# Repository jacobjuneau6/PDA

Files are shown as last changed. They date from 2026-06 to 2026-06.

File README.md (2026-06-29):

# ESP32-S3 PDA

A simple ESP32-S3 based phone companion and pocket computer. This open-source hardware project includes a custom PCB, 3D-printable case, and Arduino firmware — everything you need to build a portable device with a color TFT display, LiPo battery management, and physical navigation buttons.

## Features

- **ESP32-S3-WROOM-1-N16R8** module (16 MB flash, 8 MB PSRAM)
- **ST7789 240×320 TFT** color display with PWM backlight control
- **MAX17048** LiPo fuel gauge for accurate battery state-of-charge
- **MCP73831** Li-Ion/Li-Po battery charger (charges via USB)
- **WS2812/NeoPixel** RGB status LED
- **3 navigation buttons** (UP, SELECT, DOWN) with active-low pull-ups
- **USB micro-B** connector for power and data
- **2-layer PCB** with Gerber files ready for fabrication
- **3D-printable case** designed in FreeCAD

## Pinout

| Silkscreen | GPIO | Function |
|---|---|---|
| SCL | 2 | SPI SCLK (TFT clock) |
| SDA | 1 | SPI MOSI (TFT data) |
| CS | 3 | TFT chip select |
| DC | 4 | TFT data/command |
| RST | 5 | TFT reset |
| BL | 6 | TFT backlight PWM |
| — | 7 | WS2812 status LED (NeoPixel) |
| — | 8 | I2C SCL (MAX17048 fuel gauge) |
| — | 9 | I2C SDA (MAX17048 fuel gauge) |
| — | 10 | Button UP |
| — | 11 | Button SELECT |
| — | 12 | Button DOWN |

**Display connector:** 1×08 pin header (GND, VCC, SCL, SDA, RST, DC, CS, BL) for ST7789 240×320 TFT, 1.54″ or 1.69″ diagonal.

**I²C address:** MAX17048 at `0x36`.

## Bill of Materials

| Reference | Qty | Part | DigiKey P/N | Description | Price  |
|---|-----|---|---|---|---|
| J1 | 1 | RAHMB20AUETR | 137-RAHMB20AUETRCT-ND | USB micro-B receptacle, right-angle, SMT (Switchcraft) | |
| LED1 | 1 | COM-16347 | 568-16347CT-ND | WS2812/NeoPixel RGB LED | |
| R1, R2 | 2 | RC1206FR-132KL | 13-RC1206FR-132KLCT-ND | 2 kΩ 1206 thick-film resistor (Yageo) | |
| SW1, SW2, SW3, SW4  | 4 | B3F-1002 | SW401-ND | Tactile switch (Omron) | |
| U1 | 1 | ESP32-S3-WROOM-1-N16R8  | 5407-ESP32-S3-WROOM-1-N16R8CT-ND | ESP32-S3 module, 16 MB flash, 8 MB PSRAM | |
| U2 | 1 | MCP73831T-2DCI/MC | MCP73831T-2DCI/MCCT-ND | Li-Ion/Li-Po battery charger IC (Microchip) | |
| U3 | 1 | TPS74533PCQWDRVRQ1 | 296-TPS74533PCQWDRVRQ1CT-ND | 3.3 V LDO voltage regulator, 500 mA (TI) | |
| U4 | 1 | MAX17048G+T10 | MAX17048G+T10CT-ND | LiPo fuel gauge IC (Maxim Integrated) | |
| U5 | 1 | AO3400A | 785-1000-1-ND | N-channel MOSFET, SOT-23 (battery protection) | |
| — | 1 | Custom PCB & stencil | JLCPCB | Fabrication | $20.00 |
| — | 1 | DigiKey components | | Components & shipping | $30.00 |
| — | 1 | 1Ah battery | | https://www.amazon.com/dp/B0DPZVBKMY?th=1 | $8.00  |
| — | 1 | Display | | https://www.amazon.com/gp/product/B0DFWLD38D/ref=ox_sc_act_title_2?smid=A2UYBS1CH53PM5 | $16.00 |

## Pictures
20260629_00h41m58s_grim
20260629_00h42m06s_grim
20260629_00h42m20s_grim
20260629_00h42m29s_grim
20260629_00h42m41s_grim
20260629_00h42m50s_grim
20260629_00h43m04s_grim
## Power Architecture

```
USB VBUS (5 V)
  ├── MCP73831 charger (U2) ──→ VBAT (battery voltage)
  │     ├── AO3400A MOSFET (U5) — battery protection
  │     └── MAX17048 fuel gauge (U4) — I²C monitoring
  │
  └── TPS74533 LDO (U3) ──→ 3.3 V rail
        ├── ESP32-S3 module (U1)
        ├── Display backlight (PWM on GPIO6)
        └── Peripherals (WS2812, buttons, I²C pull-ups)
```

- The device charges a single-cell LiPo battery via USB at 4.2 V termination.
- Battery voltage and state-of-charge are monitored by the MAX17048 over I²C.
- The 3.3 V LDO powers the MCU and peripherals from either USB or battery.

## Repository Structure

```
PDA/
├── README.md              # This file
├── BOM.csv                # Bill of Materials with DigiKey part numbers
├── Journal.md             # Design journal — case design notes & images
├── LICENSE                # MIT License
│
├── board/                 # KiCad PCB design
│   ├── board.kicad_sch    # Schematic
│   ├── board.kicad_pcb    # PCB layout
│   ├── board.kicad_pro    # Project settings
│   ├── gbrs/              # Gerber files (ready for fabrication)
│   └── staging/           # Vendor symbols, footprints, and 3D models
│
├── CAD/                   # FreeCAD mechanical design
│   ├── Assembly.FCStd     # Full assembly (PCB + case + battery + display)
│   ├── case.FCStd         # 3D-printable enclosure
│   ├── battery.FCStd      # Dummy battery model (fit check)
│   ├── display.FCStd      # Dummy display model (fit check)
│   └── PCB.step           # PCB STEP export
│
└── CODE/                  # Firmware
    └── test/
        ├── platformio.ini # PlatformIO build configuration
        └── src/
            └── main.cpp   # Arduino demo sketch
```

## Firmware

The demo firmware exercises all major subsystems: display, battery gauge, status LED, and buttons.

### Build & Flash

**Prerequisites:** [PlatformIO](https://platformio.org/install) (VS Code extension or CLI).

```bash
cd CODE/test

# Build
pio run

# Flash and open serial monitor (115200 baud)
pio run --target upload --target monitor
```

### What the Demo Does

1. **Boot splash** — "ESP32-S3 PDA / Boot OK" on the TFT, WS2812 glows blue
2. **Battery readout** — cell voltage and state-of-charge, updates ~6× per second
3. **Button indicators** — shows pressed button (UP/SELECT/DOWN) on the TFT
4. **LED feedback** — WS2812 colour changes:
   - Purple = idle
   - Green = SELECT
   - Red = UP
   - Blue = DOWN
5. **Serial debug** — prints voltage, SOC, and button state at 115200 baud

### Libraries

| Library | Version |
|---|---|
| Adafruit GFX | ≥1.11 |
| Adafruit ST7735/ST7789 | ≥1.10 |
| Adafruit MAX1704X | ≥1.0 |
| FastLED | ≥3.7 |

All are fetched automatically by PlatformIO via `lib_deps`.

### Board Configuration

| Setting | Value |
|---|---|
| Board | ESP32-S3 DevKitC-1 |
| Framework | Arduino |
| Monitor baud | 115200 |

### Customisation

- **Backlight level** — call `backlightWrite(0..255)` in `loop()` (e.g., dim after inactivity)
- **Rotation** — change `tft.setRotation(1)` (0–3) if your panel is mounted differently
- **I²C pins** — edit `I2C_SDA` and `I2C_SCL` at the top of `main.cpp`

## PCB

- **Layers:** 2-layer board
- **Software:** KiCad 8
- **Gerber files:** Ready for fabrication in [`board/gbrs/`](board/gbrs/)
- **View online:** [Kicanvas](https://kicanvas.org/?github=https://github.com/jacobjuneau6/PDA/blob/main/board/board.kicad_pcb) — interactive board viewer (no KiCad install needed)

The PCB uses all surface-mount components. Most ICs are in small-outline packages (SOT-23, TDFN, WSON). The display connects via a standard 1×08 2.54 mm pitch pin header.

## Case

Designed in FreeCAD with a boxy, sharp-edged aesthetic. The case holds:
- The custom PCB
- A single-cell LiPo battery
- The ST7789 TFT display (1.54″ or 1.69″)

Dummy battery and display models are included for fit checking in the assembly.

## License

MIT License — see [LICENSE](LICENSE) for details.

Copyright (c) 2026 jacobjuneau6

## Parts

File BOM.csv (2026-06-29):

Reference | Qty | DigiKey_Part_Number
J1 | 1 | 137-RAHMB20AUETRCT-ND
LED1 | 1 | 568-16347CT-ND
R1,R2 | 2 | 13-RC1206FR-132KLCT-ND
SW1,SW2,SW3,SW4 | 4 | SW401-ND
U1 | 1 | 5407-ESP32-S3-WROOM-1-N16R8CT-ND
U2 | 1 | MCP73831T-2DCI/MCCT-ND
U3 | 1 | 296-TPS74533PCQWDRVRQ1CT-ND
U4 | 1 | MAX17048G+T10CT-ND
U5 | 1 | 785-1000-1-ND

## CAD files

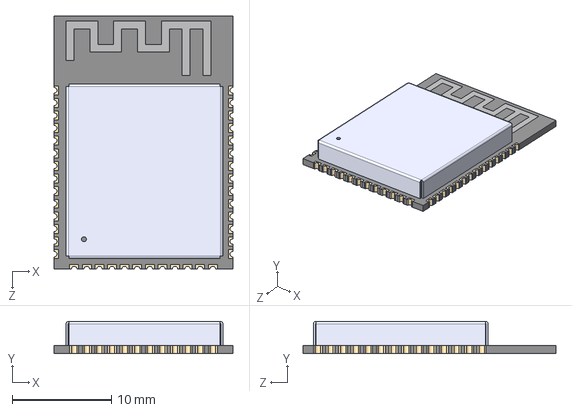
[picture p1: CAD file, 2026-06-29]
board/staging/ESP32-S3-WROOM-1-N16R8.STEP
18.0 x 3.25 x 25.5 mm

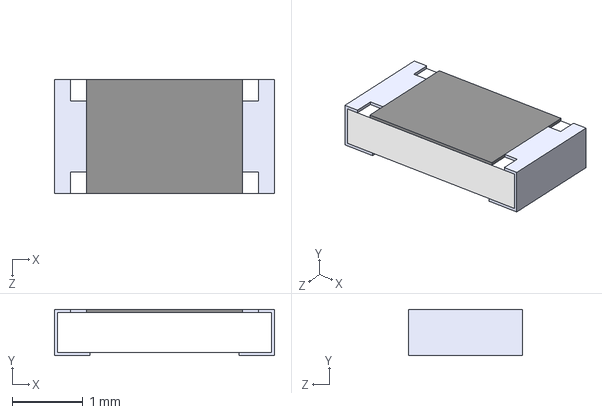
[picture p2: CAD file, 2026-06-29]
board/staging/RC1206FR-132KL/RC1206FR-132KL.step
3.10 x 0.65 x 1.60 mm

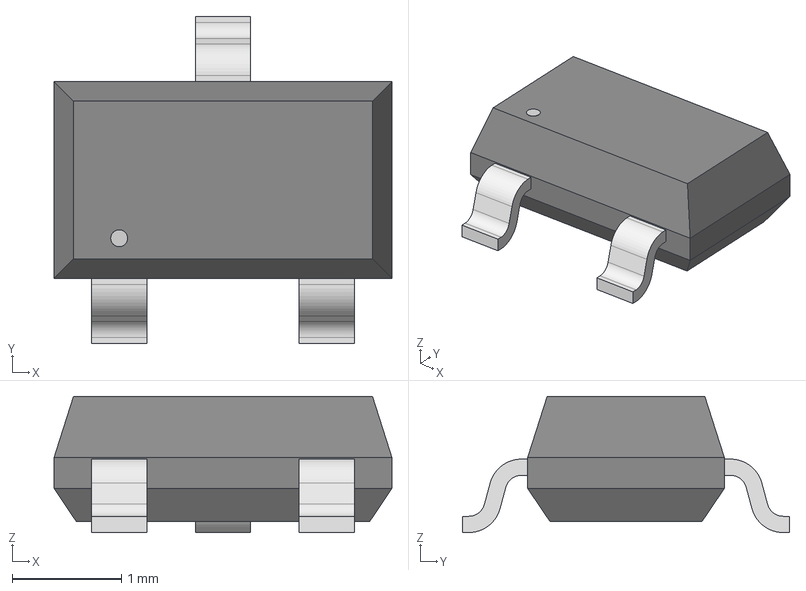
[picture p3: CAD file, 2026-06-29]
board/staging/ul_AO3400A/SOT-23-3L_AOS.step
3.10 x 3.00 x 1.25 mm

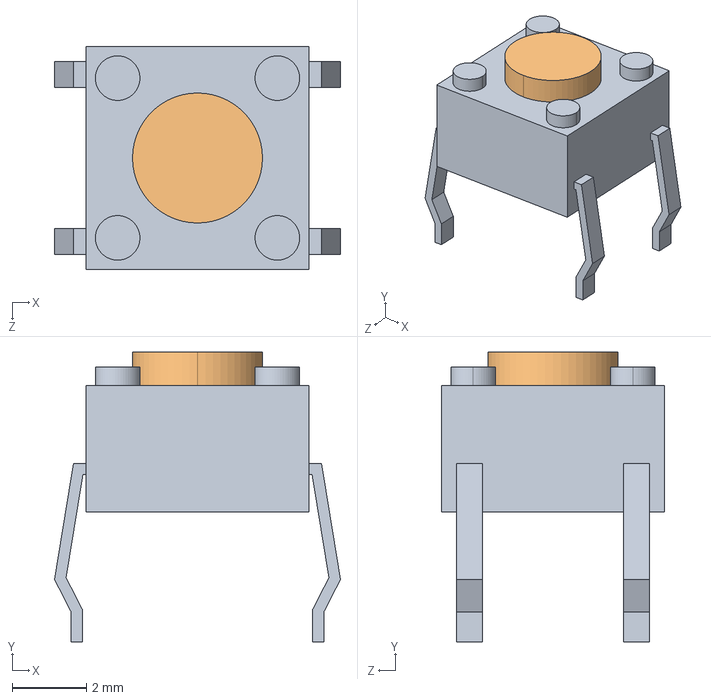
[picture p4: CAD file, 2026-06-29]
board/staging/ul_B3F-1002/B3F_1002.step
7.70 x 7.80 x 6.00 mm
B3F_1005_BASE
B3F_1005_BUTTON

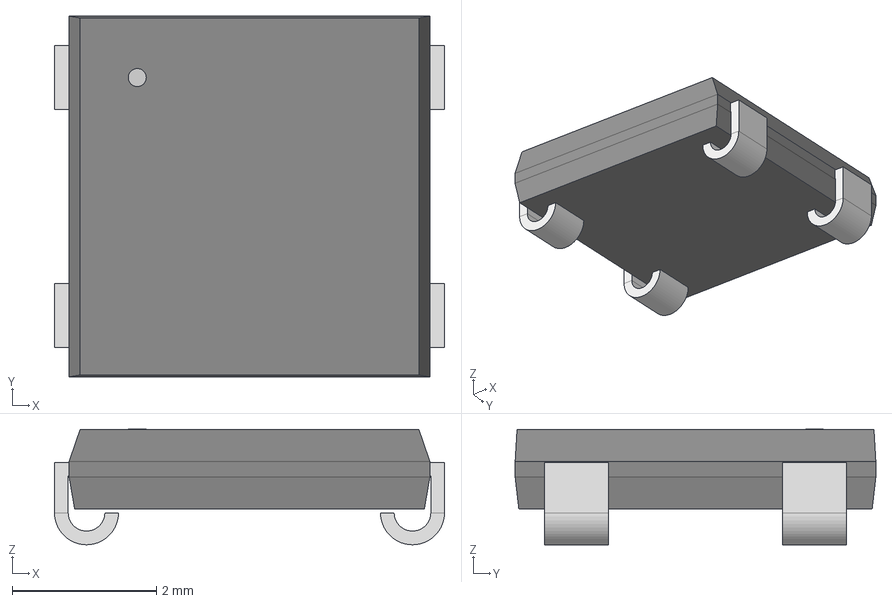
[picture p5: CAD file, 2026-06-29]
board/staging/ul_COM-16347/COM-16347_SPK.step
5.41 x 5.00 x 1.60 mm

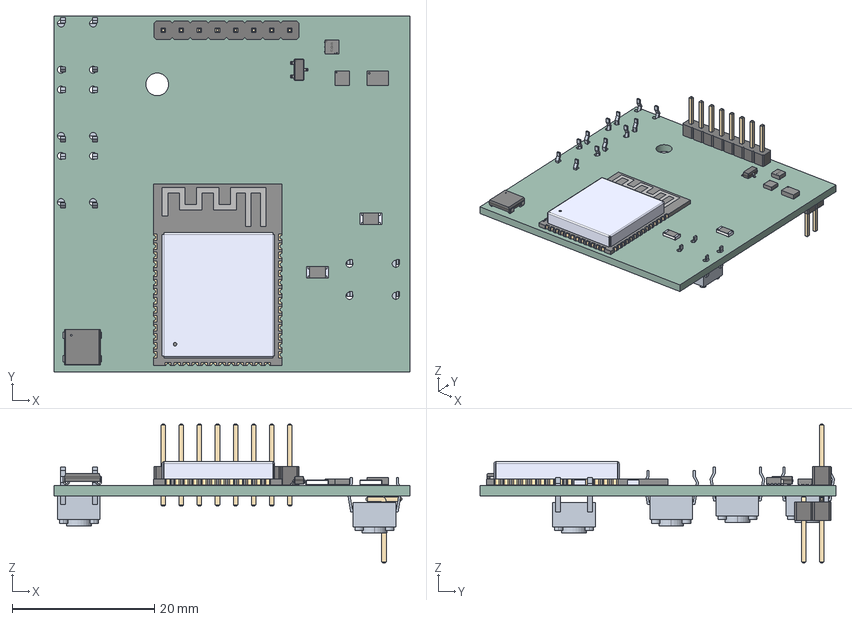
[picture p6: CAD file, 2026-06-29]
CAD/PCB.step
50.0 x 50.0 x 19.5 mm
ESP32-S3-WROOM-1-N8R2
B3F_1005_BASE x 4
B3F_1005_BUTTON x 4
MAX17048G+T10
PinHeader_1x08_P254mm_Vertical
AA1206FR-07100KL x 2
MCP73831-2ACI_MC
WSON-6_L2.0-W2.0-H0.8-P0.65
SOT-23
PinHeader_1x02_P254mm_Vertical_SMD_Pin1Left
board_PCB

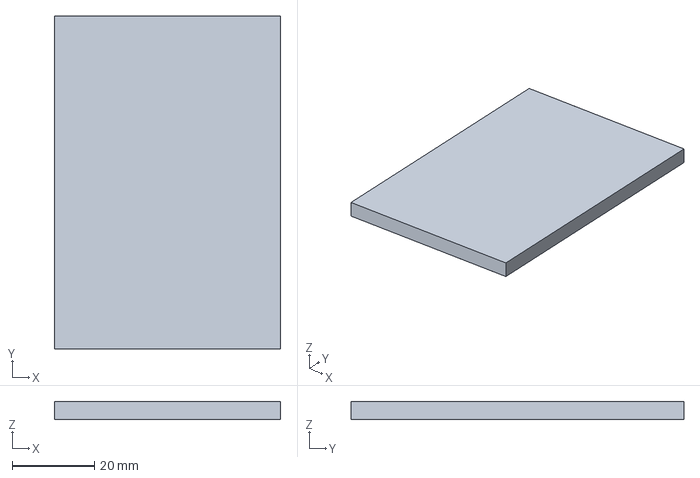
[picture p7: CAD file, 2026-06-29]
CAD/display.FCStd
55.0 x 81.0 x 4.40 mm

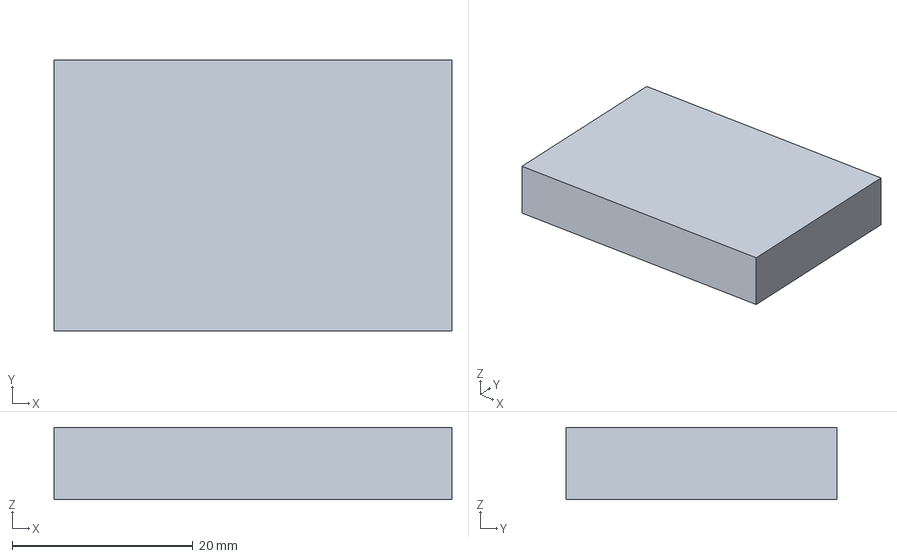
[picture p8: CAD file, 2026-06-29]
CAD/battery.FCStd
44.0 x 30.0 x 8.00 mm

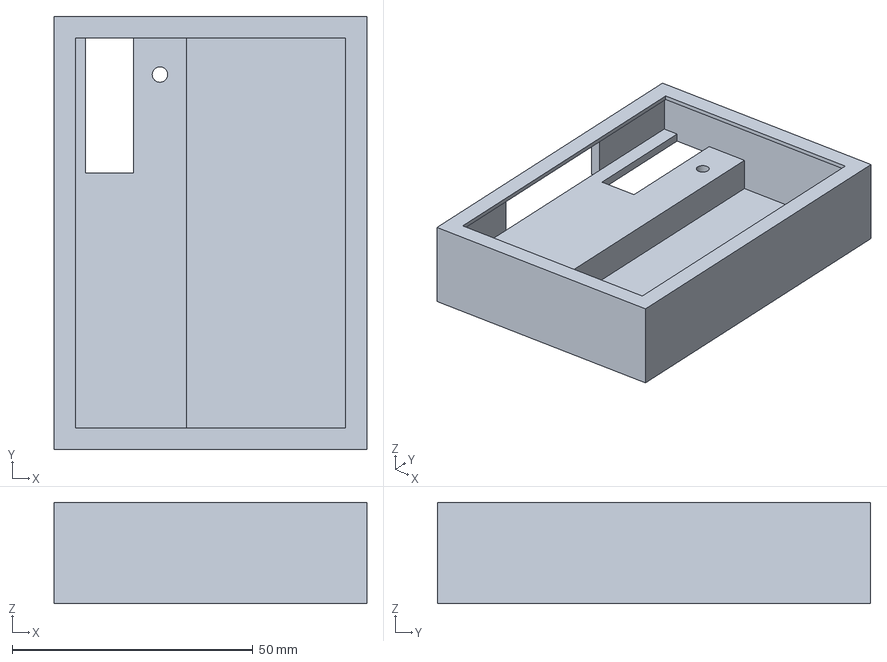
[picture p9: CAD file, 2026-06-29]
CAD/case.FCStd
65.0 x 90.0 x 21.0 mm

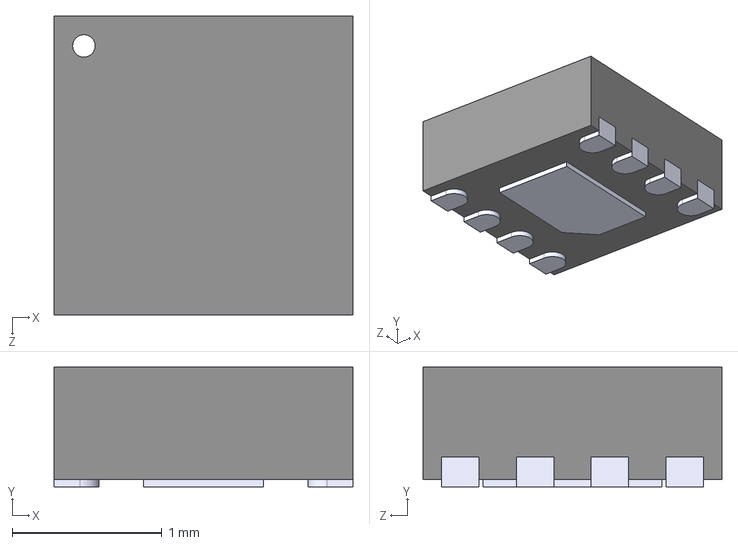
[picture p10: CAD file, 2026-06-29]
board/staging/MAX17048G_T10/MAX17048G_T10.step
2.00 x 0.8 x 2.00 mm

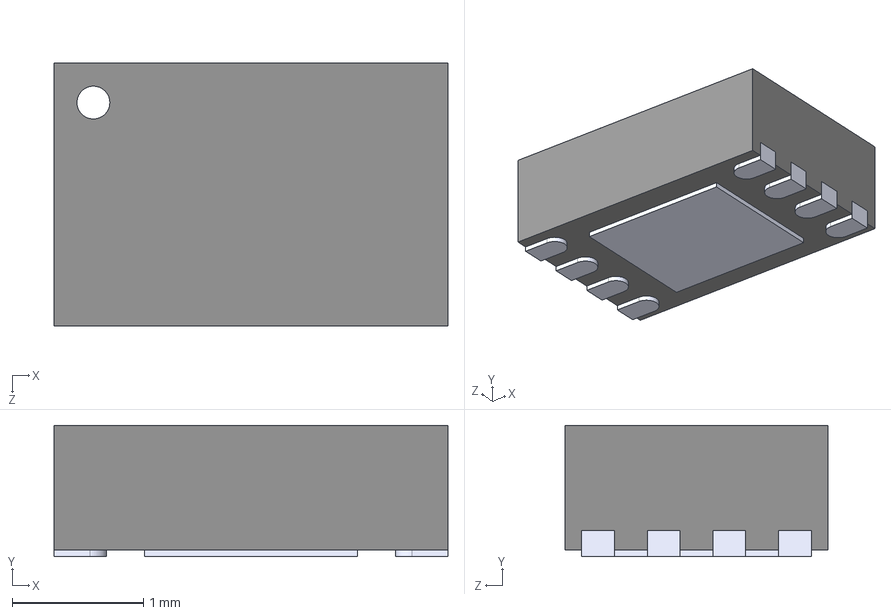
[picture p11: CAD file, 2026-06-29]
board/staging/MCP73831T-2DCI_MC/MCP73831T-2DCI_MC.step
3.00 x 1.00 x 2.00 mm

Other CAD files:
CAD/Assembly.FCStd
CAD/PCB.FCStd

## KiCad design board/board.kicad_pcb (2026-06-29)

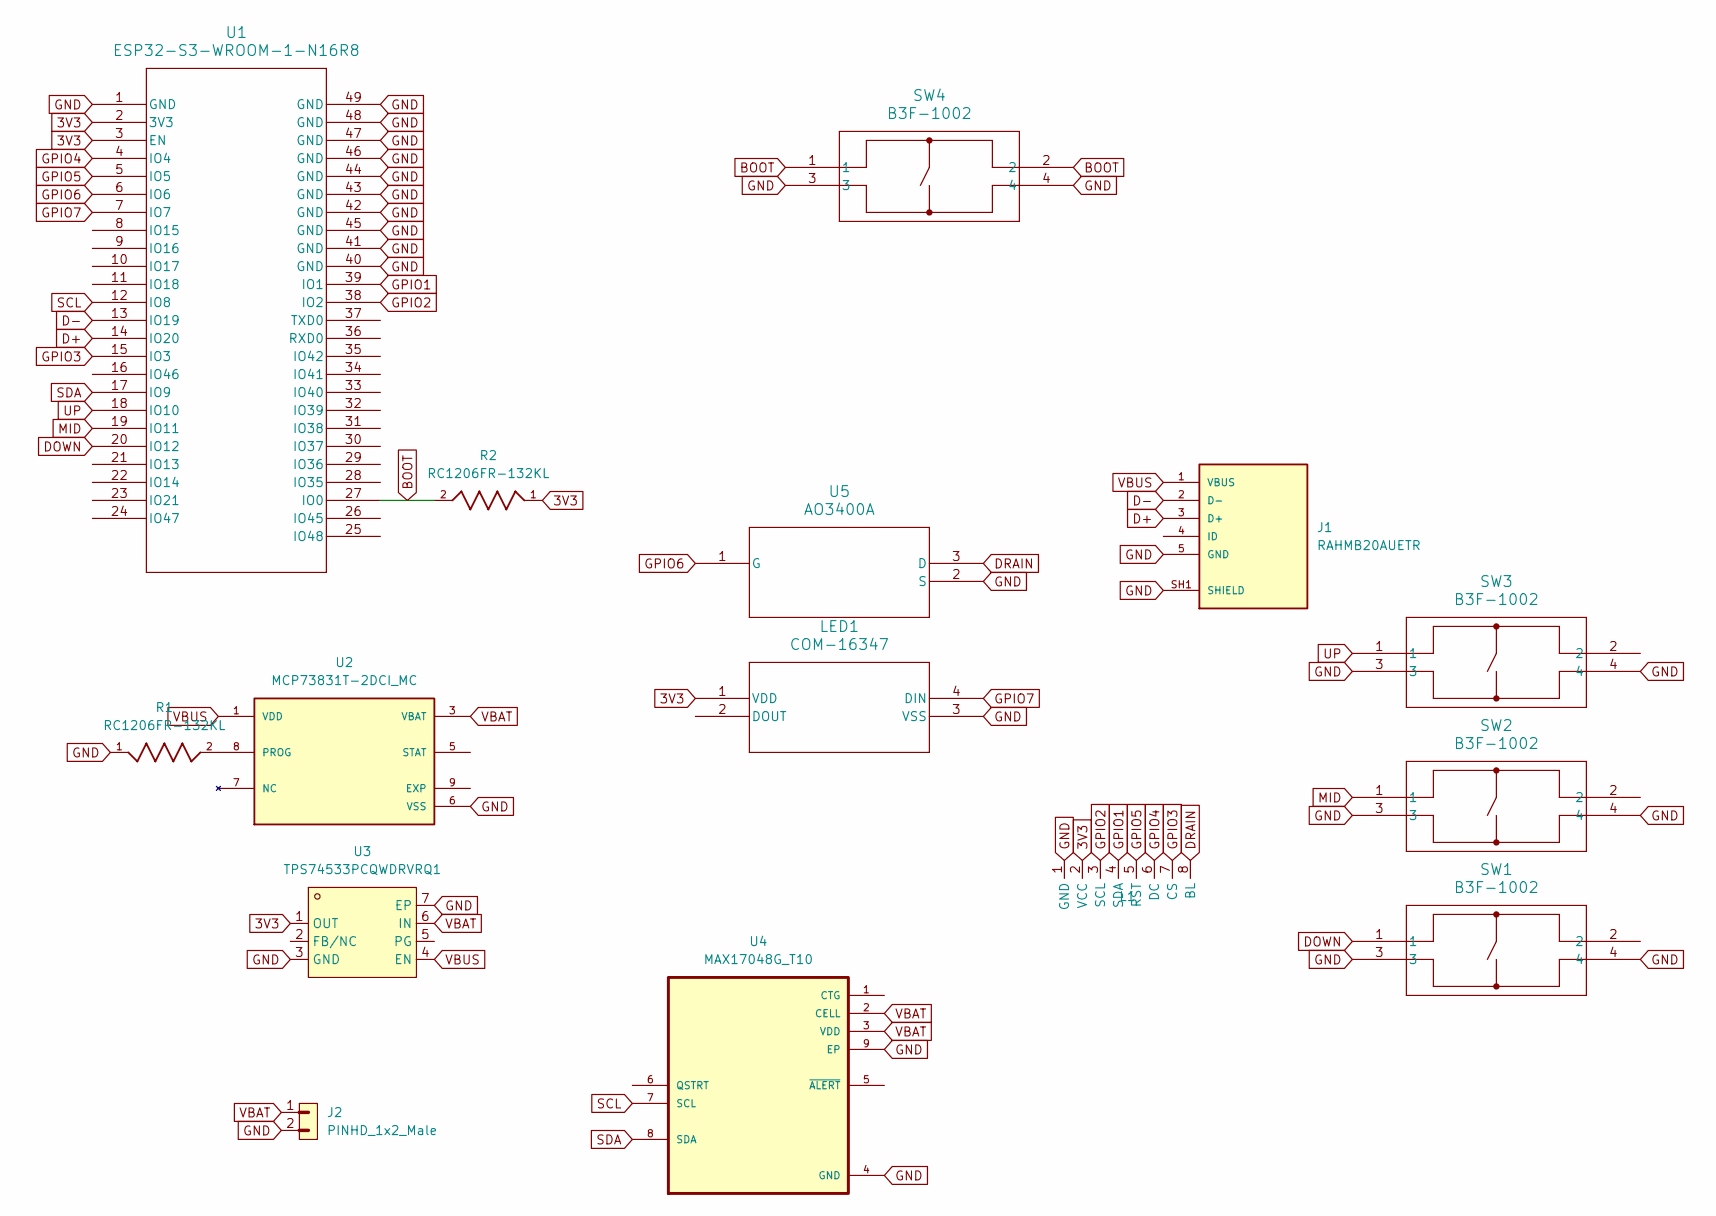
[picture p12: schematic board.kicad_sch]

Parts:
J1: RAHMB20AUETR; SWITCHCRAFT_RAHMB20AUETR; PARTREV A; DigiKey_Part_Number 137-RAHMB20AUETRCT-ND
J2: PINHD_1x2_Male; PinHeader_1x02_P2.54mm_Vertical_SMD_Pin1Left
L1: PinHeader_1x08_P2.54mm_Vertical
LED1: COM-16347; COM-16347_SPK; DigiKey_Part_Number 568-16347CT-ND
R1, R2: RC1206FR-132KL; RESC3216X65; DigiKey_Part_Number 13-RC1206FR-132KLCT-ND
SW1, SW2, SW3, SW4: B3F-1002; SW_B3F-1000_OMR; DigiKey_Part_Number SW401-ND
U1: ESP32-S3-WROOM-1-N16R8; ESP32-S3-WROOM-1_EXP; DigiKey_Part_Number 5407-ESP32-S3-WROOM-1-N16R8CT-ND
U2: MCP73831T-2DCI_MC; SON50P200X200X80-9N; PARTREV H; DigiKey_Part_Number MCP73831T-2DCI/MCCT-ND
U3: TPS74533PCQWDRVRQ1; WSON-6_L2.0-W2.0-P0.65-TL-EP; MPN TPS74533PCQWDRVRQ1; LCSC Part C2860924
U4: MAX17048G_T10; SON50P200X200X80-9N; DigiKey_Part_Number MAX17048G+T10CT-ND
U5: AO3400A; SOT-23; DigiKey_Part_Number 785-1000-1-ND

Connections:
3V3: L1.2 (VCC), LED1.1 (VDD), R2.1, U1.2 (3V3), U1.3 (EN), U3.1 (OUT)
BOOT: R2.2, SW4.1, SW4.2, U1.27 (IO0)
D+: J1.3 (D+), U1.14 (IO20)
D-: J1.2 (D-), U1.13 (IO19)
DOWN: SW1.1, U1.20 (IO12)
DRAIN: L1.8 (BL), U5.3 (D)
GND: J1.5 (GND), J1.SH1 (SHIELD), J1.SH2 (SHIELD), J1.SH3 (SHIELD), J1.SH4 (SHIELD), J1.SH5 (SHIELD), J1.SH6 (SHIELD), J2.2, L1.1 (GND), LED1.3 (VSS), R1.1, SW1.3, SW1.4, SW2.3, SW2.4, SW3.3, SW3.4, SW4.3, SW4.4, U1.1 (GND), U1.40 (GND), U1.41 (GND), U1.42 (GND), U1.43 (GND), U1.44 (GND), U1.45 (GND), U1.46 (GND), U1.47 (GND), U1.48 (GND), U1.49 (GND), U2.6 (VSS), U3.3 (GND), U3.7 (EP), U4.4 (GND), U4.9 (EP), U5.2 (S)
GPIO1: L1.4 (SDA), U1.39 (IO1)
GPIO2: L1.3 (SCL), U1.38 (IO2)
GPIO3: L1.7 (CS), U1.15 (IO3)
GPIO4: L1.6 (DC), U1.4 (IO4)
GPIO5: L1.5 (RST), U1.5 (IO5)
GPIO6: U1.6 (IO6), U5.1 (G)
GPIO7: LED1.4 (DIN), U1.7 (IO7)
MID: SW2.1, U1.19 (IO11)
unnamed: R1.2, U2.8 (PROG)
SCL: U1.12 (IO8), U4.7 (SCL)
SDA: U1.17 (IO9), U4.8 (SDA)
UP: SW3.1, U1.18 (IO10)
VBAT: J2.1, U2.3 (VBAT), U2.4 (VBAT), U3.6 (IN), U4.2 (CELL), U4.3 (VDD)
VBUS: J1.1 (VBUS), U2.1 (VDD), U2.2 (VDD), U3.4 (EN)

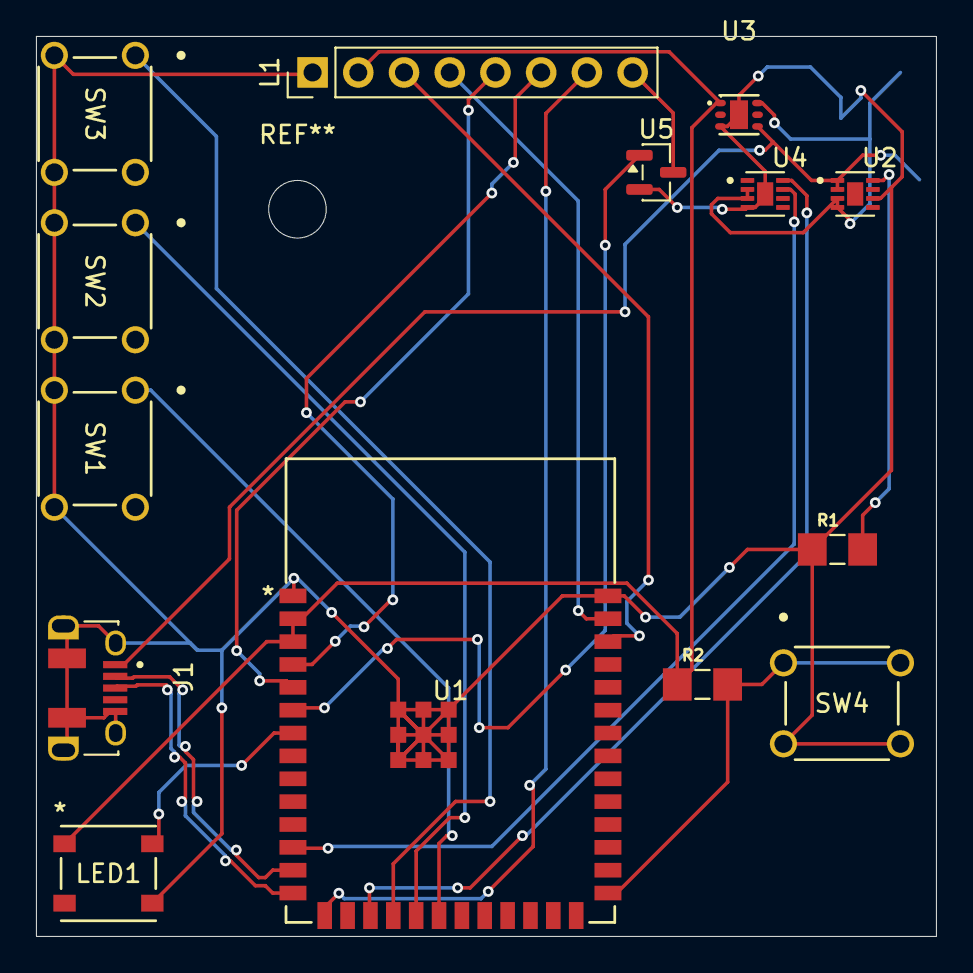
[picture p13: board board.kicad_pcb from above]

Board: 2 copper layers, 50.0 x 50.0 mm, 15 parts (1 on the bottom side), 21 nets.

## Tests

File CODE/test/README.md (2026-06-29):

# ESP32-S3 PDA — Demo Firmware

Minimal Arduino demo for the custom **ESP32-S3 PDA** board. Drives the ST7789 display, reads the MAX17048 battery gauge, lights the WS2812 status LED, and responds to the three navigation buttons.

## Hardware

| Silkscreen | GPIO | Function |
|---|---|---|
| SCL | 2 | SPI SCLK (TFT clock) |
| SDA | 1 | SPI MOSI (TFT data) |
| CS | 3 | TFT chip select |
| DC | 4 | TFT data/command |
| RST | 5 | TFT reset |
| BL | 6 | TFT backlight PWM |
| — | 7 | WS2812 status LED |
| — | 8 | I2C SCL (MAX17048) |
| — | 9 | I2C SDA (MAX17048) |
| — | 10 | Button UP |
| — | 11 | Button SELECT |
| — | 12 | Button DOWN |

**Display:** ST7789 240×320 TFT, 1.54″ or 1.69″  
**Fuel gauge:** MAX17048 (I²C addr 0x36)  
**LED:** WS2812/NeoPixel (single)

## Project Structure

```
test/
├── platformio.ini    # PlatformIO build config
├── src/
│   └── main.cpp      # Demo sketch
└── README.md
```

## Build & Flash

### Prerequisites

1. Install [PlatformIO](https://platformio.org/install) (VS Code extension or CLI).
2. Connect the ESP32-S3 board via USB.

```bash
# Clone / enter the project
cd test

# Build
pio run

# Flash & open serial monitor
pio run --target upload --target monitor
```

### Settings

| Setting | Value |
|---|---|
| Board | ESP32-S3 DevKitC-1 |
| Framework | Arduino |
| Monitor baud | 115200 |

## What the Demo Does

1. **Boot splash** — "ESP32-S3 PDA / Boot OK" on the TFT, WS2812 glows blue.
2. **Battery readout** — displays cell voltage and state-of-charge (updates ~6×/sec).
3. **Button indicators** — shows which button is pressed on the TFT.
4. **LED feedback** — WS2812 changes colour:
   - Purple = idle
   - Green = SELECT
   - Red = UP
   - Blue = DOWN
5. **Serial debug** — prints voltage, SOC, and button states at 115200 baud.

## Libraries Used

| Library | Version |
|---|---|
| Adafruit GFX | ≥1.11 |
| Adafruit ST7735/ST7789 | ≥1.10 |
| Adafruit MAX1704X | ≥1.0 |
| FastLED | ≥3.7 |

All are fetched automatically by PlatformIO (see `platformio.ini` → `lib_deps`).

## Customisation

- **Backlight level** — call `backlightWrite(0..255)` in `loop()`, e.g. to dim after inactivity.
- **Rotation** — change `tft.setRotation(1)` (0–3) if your panel is mounted differently.
- **I²C pins** — edit `I2C_SDA` / `I2C_SCL` at the top of `main.cpp`.

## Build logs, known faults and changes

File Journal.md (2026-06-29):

# The Case
After designing the PCB, I need a case to hold it that battery and the display. I made dummy stand-ins for the battery and display so i could make the assembly and do fit checks. The case design took about 1 hour and while it is not my best work, a quick 3d print of the shape feels fine so i say its good enough. 
I chose to use a more boxy-sharp design simplybecause i think that rounded edges and bevels are not stylish or useful.
# Pictures of the design
20260629_00h41m58s_grim
20260629_00h42m06s_grim
20260629_00h42m20s_grim
20260629_00h42m29s_grim
20260629_00h42m41s_grim
20260629_00h42m50s_grim
20260629_00h43m04s_grim

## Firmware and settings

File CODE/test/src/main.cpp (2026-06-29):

/**
 * ESP32-S3 PDA — Demo Sketch
 *
 * Hardware:
 *   - ST7789 240×320 TFT (software SPI)
 *   - MAX17048 LiPo fuel gauge (I2C)
 *   - WS2812 status LED
 *   - 3 navigation buttons (UP / SELECT / DOWN)
 *
 * Pin mapping (matches custom PDA board):
 *   GPIO1  = SDA  → SPI MOSI
 *   GPIO2  = SCL  → SPI SCLK
 *   GPIO3  = CS   → Chip select
 *   GPIO4  = DC   → Data/command
 *   GPIO5  = RST  → Reset
 *   GPIO6  = BL   → Backlight PWM
 *   GPIO7  = WS2812 data
 *   GPIO8  = I2C SCL
 *   GPIO9  = I2C SDA
 *   GPIO10 = Button UP
 *   GPIO11 = Button SELECT
 *   GPIO12 = Button DOWN
 */

#include <Arduino.h>
#include <Wire.h>
#include <Adafruit_GFX.h>
#include <Adafruit_ST7789.h>
#include <Adafruit_MAX1704X.h>
#include <FastLED.h>

// ---------------------------------------------------------------------------
// Display — software SPI (matches user pin table)
// ---------------------------------------------------------------------------
#define TFT_MOSI   1    // SDA on silkscreen
#define TFT_SCLK   2    // SCL on silkscreen
#define TFT_CS     3
#define TFT_DC     4
#define TFT_RST    5
#define TFT_BL     6    // Backlight PWM

Adafruit_ST7789 tft = Adafruit_ST7789(TFT_CS, TFT_DC, TFT_MOSI, TFT_SCLK, TFT_RST);

// ---------------------------------------------------------------------------
// I2C — MAX17048 fuel gauge
// ---------------------------------------------------------------------------
#define I2C_SDA    9
#define I2C_SCL    8

Adafruit_MAX17048 max17048;

// ---------------------------------------------------------------------------
// WS2812 status LED
// ---------------------------------------------------------------------------
#define LED_PIN    7
#define NUM_LEDS   1
CRGB leds[NUM_LEDS];

// ---------------------------------------------------------------------------
// Navigation buttons (active-low with pull-ups)
// ---------------------------------------------------------------------------
#define BTN_UP      10
#define BTN_SELECT  11
#define BTN_DOWN    12

// ---------------------------------------------------------------------------
// Backlight PWM
// ---------------------------------------------------------------------------
#define BL_CHANNEL  0       // LEDC channel
#define BL_FREQ     5000    // 5 kHz
#define BL_RES      8       // 8-bit resolution (0–255)

// ---------------------------------------------------------------------------
// Helpers
// ---------------------------------------------------------------------------

void backlightWrite(uint8_t duty) {
  ledcWrite(BL_CHANNEL, duty);
}

// ---------------------------------------------------------------------------
// SETUP
// ---------------------------------------------------------------------------
void setup() {
  Serial.begin(115200);
  delay(500);  // let USB serial enumerate

  Serial.println(F("\n=== ESP32-S3 PDA — Demo ===\n"));

  // ---- Buttons ----
  pinMode(BTN_UP,     INPUT_PULLUP);
  pinMode(BTN_SELECT, INPUT_PULLUP);
  pinMode(BTN_DOWN,   INPUT_PULLUP);

  // ---- WS2812 ----
  FastLED.addLeds<NEOPIXEL, LED_PIN>(leds, NUM_LEDS);
  leds[0] = CRGB::Blue;
  FastLED.show();

  // ---- Backlight PWM ----
  ledcSetup(BL_CHANNEL, BL_FREQ, BL_RES);
  ledcAttachPin(TFT_BL, BL_CHANNEL);
  backlightWrite(128);  // 50 % brightness at boot

  // ---- I2C + MAX17048 ----
  Wire.begin(I2C_SDA, I2C_SCL);
  if (!max17048.begin()) {
    Serial.println(F("⚠ MAX17048 not detected — check I2C wiring"));
  } else {
    Serial.println(F("✓ MAX17048 OK"));
  }

  // ---- Display ----
  tft.init(240, 320);                 // 240 wide × 320 tall
  tft.setRotation(1);                 // landscape (USB port right)
  tft.fillScreen(ST77XX_BLACK);
  tft.setTextColor(ST77XX_WHITE);
  tft.setTextSize(2);
  tft.setTextWrap(true);

  tft.setCursor(10, 10);
  tft.println("ESP32-S3 PDA");
  tft.println("Boot OK");

  // Hardware summary
  tft.setTextSize(1);
  tft.setCursor(10, 70);
  tft.println("ST7789 240x320 TFT");
  tft.setCursor(10, 82);
  tft.println("MAX17048 fuel gauge");
  tft.setCursor(10, 94);
  tft.println("WS2812 status LED");
  tft.setCursor(10, 106);
  tft.println("GPIO1-6  display bus");
  tft.setCursor(10, 118);
  tft.println("GPIO8-9  I2C bus");

  backlightWrite(255);  // full brightness
  delay(1500);
}

// ---------------------------------------------------------------------------
// LOOP
// ---------------------------------------------------------------------------
void loop() {
  // ---- Read buttons (active-low → invert) ----
  bool up   = !digitalRead(BTN_UP);
  bool sel  = !digitalRead(BTN_SELECT);
  bool down = !digitalRead(BTN_DOWN);

  // ---- Battery ----
  float voltage = 0.0f;
  float soc     = 0.0f;
  bool  gaugeOk = max17048.begin();  // true if already init'd

  if (gaugeOk) {
    voltage = max17048.cellVoltage();
    soc     = max17048.cellPercent();
  }

  // ---- Clear info area ----
  tft.fillRect(0, 55, 240, 100, ST77XX_BLACK);

  // ---- Voltage & SOC ----
  tft.setTextSize(2);
  tft.setCursor(10, 60);
  if (gaugeOk) {
    tft.print("V:  ");
    tft.print(voltage, 2);
    tft.print(" V");

    tft.setCursor(10, 85);
    tft.print("SOC: ");
    tft.print(soc, 1);
    tft.print(" %");
  } else {
    tft.print("MAX17048 N/C");
  }

  // ---- Button state ----
  tft.setCursor(10, 115);
  tft.print("BTN: ");
  if (up)   tft.print("UP ");
  if (sel)  tft.print("SEL ");
  if (down) tft.print("DN ");
  if (!up && !sel && !down) tft.print("—");

  // ---- WS2812 colour by button ----
  if (sel) {
    leds[0] = CRGB::Green;
  } else if (up) {
    leds[0] = CRGB::Red;
  } else if (down) {
    leds[0] = CRGB::Blue;
  } else {
    leds[0] = CRGB::Purple;
  }
  FastLED.show();

  // ---- Serial debug ----
  Serial.printf("V=%.2f  SOC=%.1f%%  UP=%d SEL=%d DN=%d\n",
                voltage, soc, up, sel, down);

  delay(150);
}

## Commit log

2026-06-29 ADD PCB & CAD
    [Assembly.FCStd, B3F_1002.step, COM-16347_SPK.step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]
2026-06-29 Add journal entry for PCB case design and images
    Documented the case design for the PCB assembly, including fit checks and design choices. Added images of the design for reference.
2026-06-29 add gerbers and BOM
    [BOM.csv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]
2026-06-29 Enhance Bill of Materials with pricing details
    Updated the Bill of Materials table to include prices and additional components.
